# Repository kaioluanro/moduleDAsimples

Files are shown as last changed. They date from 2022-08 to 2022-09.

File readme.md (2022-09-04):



# Module D/A signal audio

Hi, it's project the module for input/output signal to computer signal.

# Features

- 5V or 3.3v power supply;
- ADC: 24bit;
- Frequence samples ADC max: 128;
- DAC: 24bit or 32bit;
- Frequence samples DAC max: 64;
- Stereo Input signal audio;
- Stereo Output signal audio;
- Connection  via i2s;

## Application 

Used for signal the audio purpose.

## Function Diagram
```mermaid
sequenceDiagram
INPUT ->> ADC: Signal
ADC->>PROCESS: 24-bits
Note over PROCESS: Process signal digital.
PROCESS->> DAC: 24-bits or 32-bits
DAC->> OUTPUT: Signal

```

## Alert
module still in test and subject to change.

## I2S for Blackpill(STM32F411CEU6)
The STMicroelectronics provides an documention know emulation I2S used SPI and TIMER. overview in the link [Emulation I2S](https://www.st.com/resource/en/application_note/an5086-i2s-protocol-emulation-on-stm32l0-series-microcontrollers-using-a-standard-spi-peripheral-stmicroelectronics.p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).

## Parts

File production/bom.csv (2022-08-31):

Designator | Footprint | Quantity | Value | LCSC Part #
C11 | C_0603_1608Metric | 1 | 100n | C80516
J7 | PinHeader_1x04_P1.27mm_Vertical | 1 | Conn_01x04 | C2935944
C7 | CP_EIA-3216-18_Kemet-A | 1 | 10u | C7171
U1 | TSSOP-20_4.4x6.5mm_P0.65mm | 1 | PCM5100APWR | C131154
C9 | CP_EIA-3216-18_Kemet-A | 1 | 10u | C7171
C4 | C_0603_1608Metric | 1 | 2.2u | C913904
C16 | CP_EIA-3216-18_Kemet-A | 1 | 10u | C7171
J6 | PinHeader_2x04_P1.27mm_Vertical | 1 | Conn_02x04_Counter_Clockwise | C541878
F1 | C_1812_4532Metric | 1 | mSMD110-16V | C69691
C22 | CP_EIA-3216-18_Kemet-A | 1 | 10u | C7171
C1 | C_0603_1608Metric | 1 | 1u | C1689
J5 | Jack_6.35mm_Neutrik_NMJ6HFD2-AU_Horizontal | 1 | PJ-625C | C309291
J2 | Jack_6.35mm_Neutrik_NMJ6HFD2-AU_Horizontal | 1 | PJ-625C | C309291
R10 | R_0603_1608Metric | 1 | 100k | C14675
C17 | C_0603_1608Metric | 1 | 100n | C80516
J1 | Jack_6.35mm_Neutrik_NMJ6HFD2-AU_Horizontal | 1 | PJ-625C | C309291
J4 | Jack_6.35mm_Neutrik_NMJ6HFD2-AU_Horizontal | 1 | PJ-625C | C309291
C5 | C_0805_2012Metric | 1 | 0.1u | C126469
D1 | D_SOD-123 | 1 | ZRE B5819W-SL | C779676
C23 | C_0603_1608Metric | 1 | 1u | C1689
C24 | C_1210_3225Metric | 1 | 10u | C92769
J3 | PinHeader_1x04_P1.27mm_Vertical | 1 | Conn_01x04 | C2935944
C14 | C_0805_2012Metric | 1 | 0.1u | C126469
C13 | C_0805_2012Metric | 1 | 0.1u | C126469
C20 | CP_EIA-3216-18_Kemet-A | 1 | 10u | C7171
R4 | R_0603_1608Metric | 1 | 5.1k | C156350
C6 | CP_EIA-3216-18_Kemet-A | 1 | 10u | C7171
R1 | R_0805_2012Metric | 1 | 2k | C269745
C25 | C_0603_1608Metric | 1 | 1u | C1689
R5 | R_0603_1608Metric | 1 | 3.3k | C72816
U2 | SSOP-20_5.3x7.2mm_P0.65mm | 1 | WM8782SEDS | C323842
U3 | SOT-23-5 | 1 | SGM2028-3.3YN5G/TR | C81088
R3 | R_0603_1608Metric | 1 | 10K | C99198
C12 | C_0603_1608Metric | 1 | 100n | C80516
R9 | R_0603_1608Metric | 1 | 100k | C14675
J8 | PinHeader_1x04_P1.27mm_Vertical | 1 | Conn_01x04 | C2935944
C21 | CP_EIA-3216-18_Kemet-A | 1 | 10u | C7171
C8 | C_0805_2012Metric | 1 | 0.1u | C126469
C2 | C_0603_1608Metric | 1 | 1u | C1689
C18 | C_0603_1608Metric | 1 | 100n | C80516
R8 | R_0603_1608Metric | 1 | 10k | C99198
R2 | R_0805_2012Metric | 1 | 2k | C269745
C10 | CP_EIA-3216-18_Kemet-A | 1 | 10u | C7171
C19 | CP_EIA-3216-18_Kemet-A | 1 | 10u | C7171
R7 | R_0603_1608Metric | 1 | 5.1k | C156350
C15 | CP_EIA-3216-18_Kemet-A | 1 | 10u | C7171
R6 | R_0603_1608Metric | 1 | 10k | C99198
C3 | C_0603_1608Metric | 1 | 2.2u | C913904

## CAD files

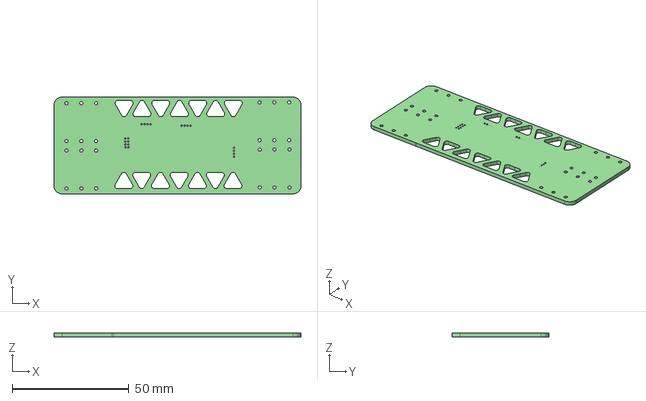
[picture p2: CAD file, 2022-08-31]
Modulo DA simple.step
105.9 x 41.5 x 1.60 mm

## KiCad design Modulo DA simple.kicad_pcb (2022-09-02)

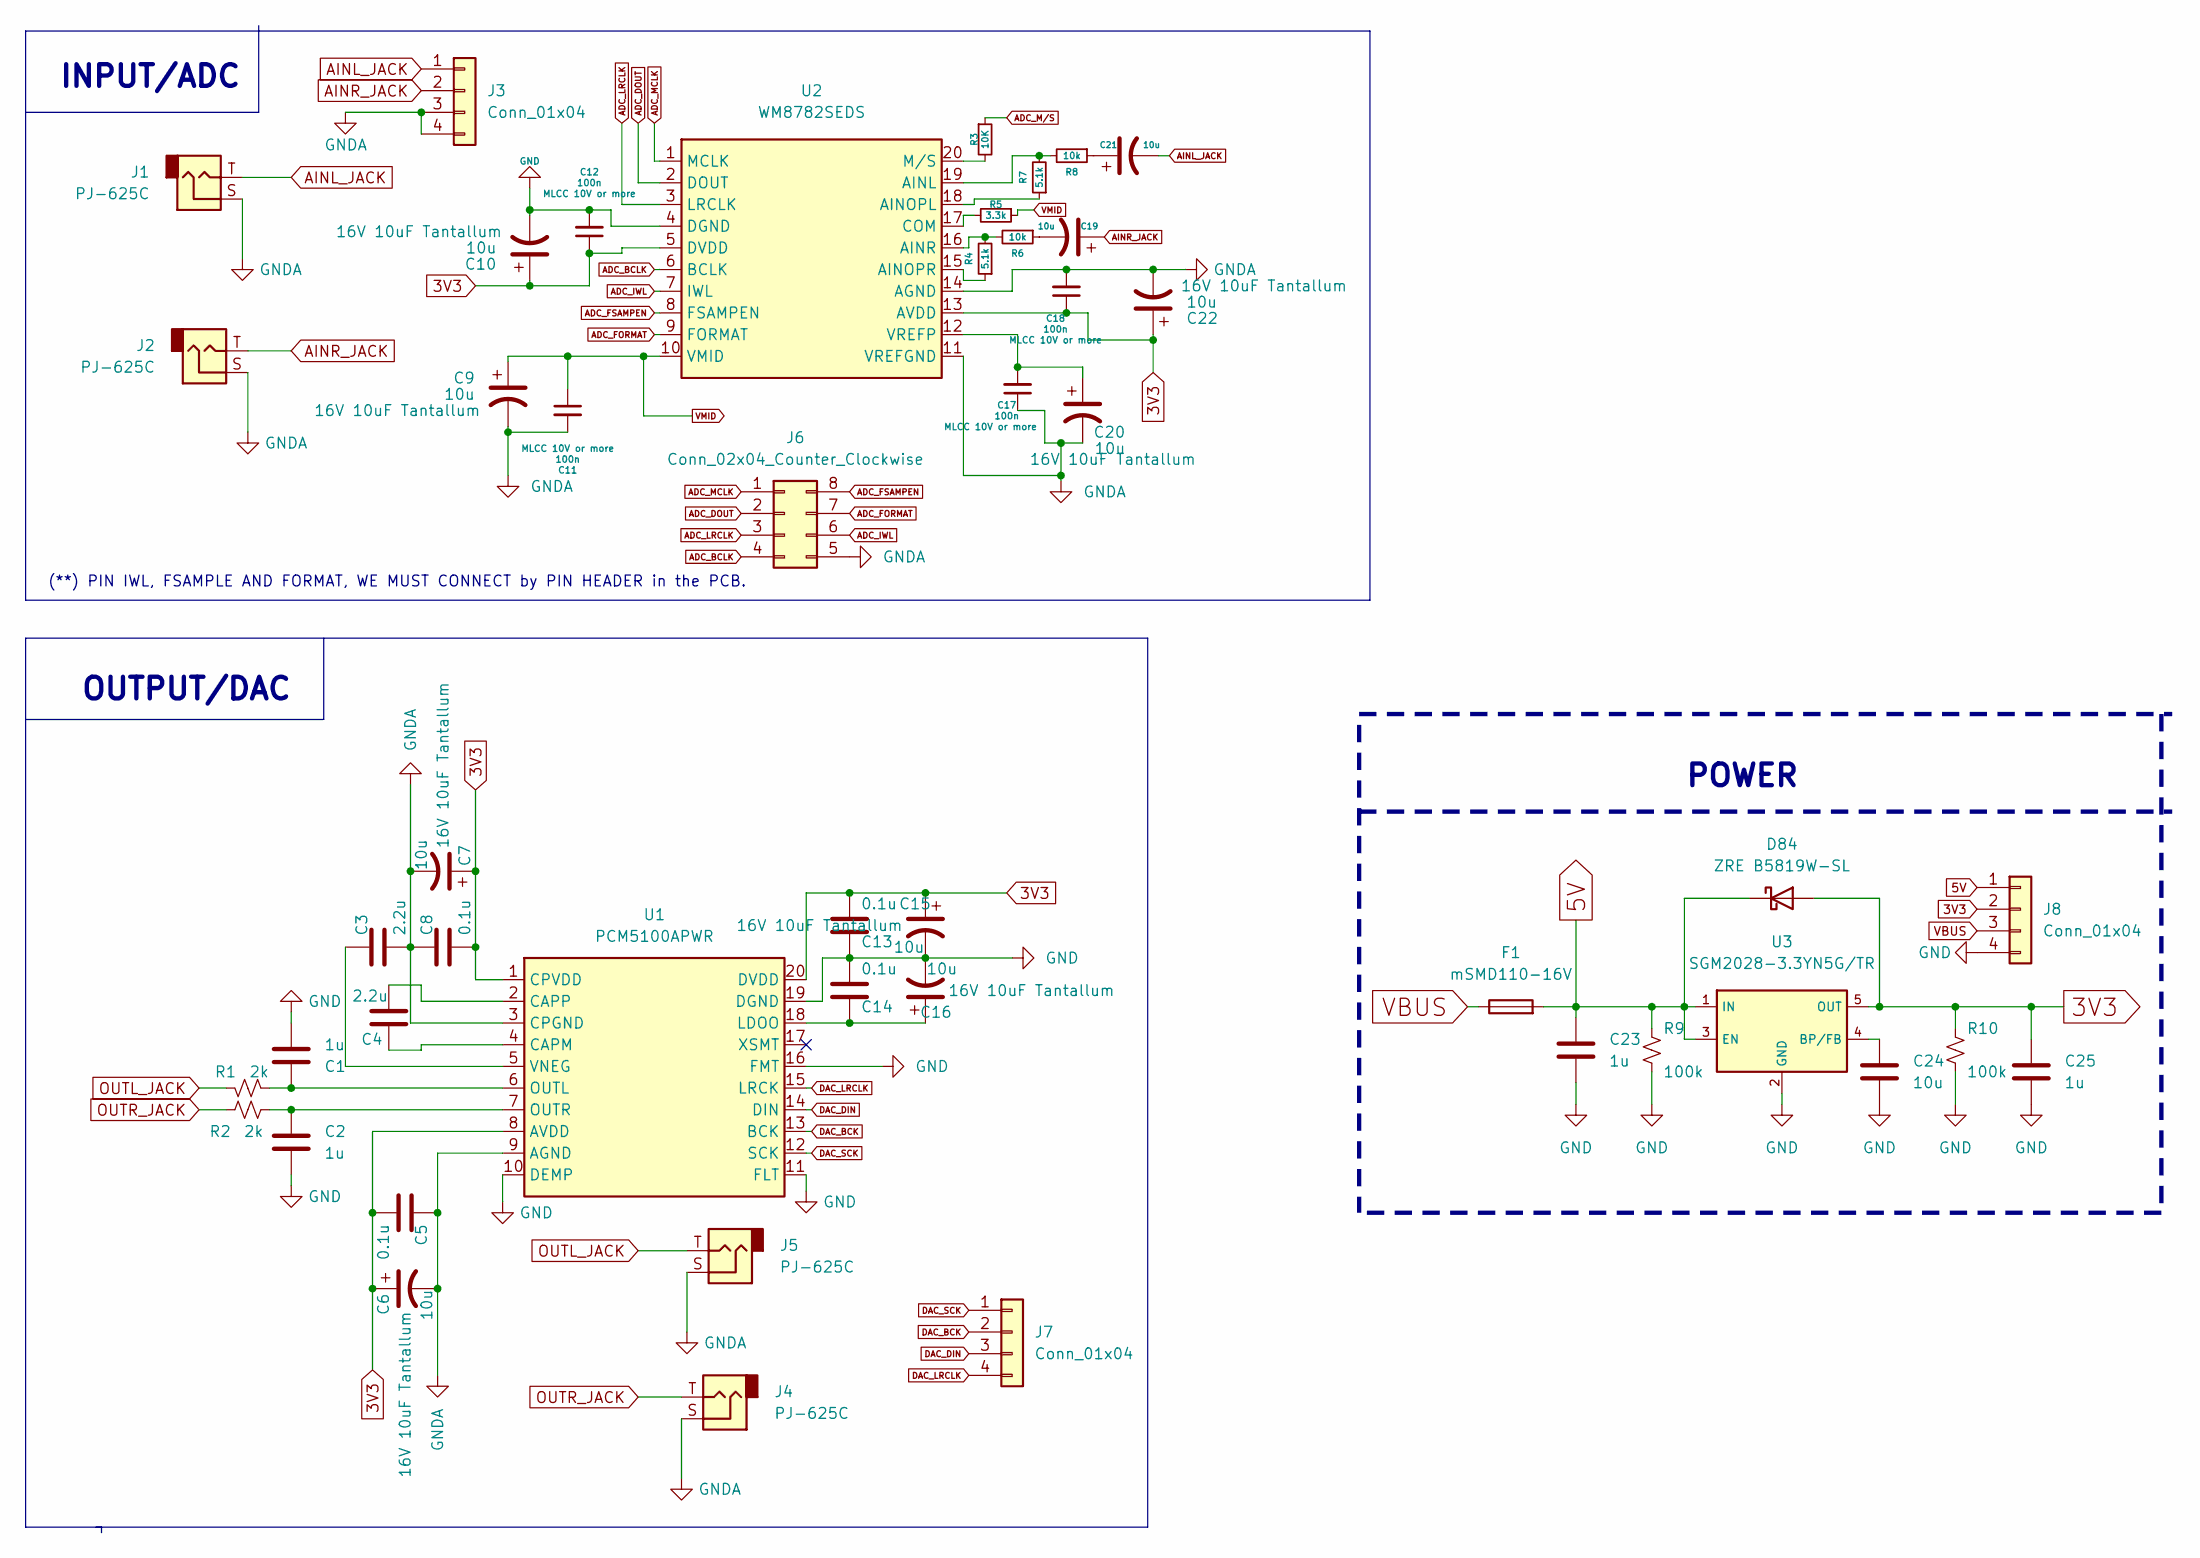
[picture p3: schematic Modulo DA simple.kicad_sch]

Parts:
C1, C2, C23, C25: 1u; C_0603_1608Metric; Manufacturer Part Number 0603F105M160NT; LCSC Part # C1689
C3, C4: 2.2u; C_0603_1608Metric; Manufacturer Part Number CL10A225KB8NNNC; LCSC Part # C913904
C5, C8, C13, C14: 0.1u; C_0805_2012Metric; Manufacturer Part Number UMK107AB7105KA-T; LCSC Part # C126469
C6, C7, C9, C10, C15, C16, C19, C20, C21, C22: 10u; CP_EIA-3216-18_Kemet-A; Manufacturer Part Number TAJA106K016RNJ; LCSC Part # C7171
C11, C12, C17, C18: 100n; C_0603_1608Metric; Manufacturer Part Number 0603B104K160CT; LCSC Part # C80516
C24: 10u; C_1210_3225Metric; Manufacturer Part Number EMK325BJ106KN-T; LCSC Part # C92769
D84: ZRE B5819W-SL; D_SOD-123; Manufacturer Part Number B5819W-SL; LCSC Part # C779676
F1: mSMD110-16V; C_1812_4532Metric; Manufacturer Part Number mSMD110-16V; LCSC Part # C69691
J1, J2, J4, J5: PJ-625C; Jack_6.35mm_Neutrik_NMJ6HFD2-AU_Horizontal; Manufacturer Part Number PJ-625C; LCSC Part # C309291
J3, J7, J8: Conn_01x04; PinHeader_1x04_P1.27mm_Horizontal; Manufacturer Part Number DZ127R-11-04-25; LCSC Part # C2935944
J6: Conn_02x04_Counter_Clockwise; PinHeader_2x04_P1.27mm_Horizontal; Manufacturer Part Number PZ127V-12-08-0720; LCSC Part # C541878
R1, R2: 2k; R_0805_2012Metric; Manufacturer Part Number RMC08052K1%N; LCSC Part # C269745
R3: 10K; R_0603_1608Metric; Manufacturer Part Number RC0603JR-0710KL; LCSC Part # C99198
R4, R7: 5.1k; R_0603_1608Metric; Manufacturer Part Number RS-03K5101FT; LCSC Part # C156350
R5: 3.3k; R_0603_1608Metric; Manufacturer Part Number RS-03K332JT; LCSC Part # C72816
R6, R8: 10k; R_0603_1608Metric; Manufacturer Part Number RC0603JR-0710KL; LCSC Part # C99198
R9, R10: 100k; R_0603_1608Metric; Manufacturer Part Number RC0603FR-07100KL; LCSC Part # C14675
U1: PCM5100APWR; TSSOP-20_4.4x6.5mm_P0.65mm; Manufacturer Part Number PCM5100APWR; LCSC Part # C131154
U2: WM8782SEDS; SSOP-20_5.3x7.2mm_P0.65mm; Manufacturer Part Number WM8782SEDS; LCSC Part # C323842
U3: SGM2028-3.3YN5G/TR; SOT-23-5; Manufacturer Part Number SGM2028-3.3YN5G/TR; LCSC Part # C81088

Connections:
3V3: C5.2, C6.1, C7.1, C8.2, C10.1, C12.1, C13.2, C15.1, C18.1, C22.1, C25.1, D84.2 (A), J8.2, R10.1, U1.1 (CPVDD), U1.8 (AVDD), U1.20 (DVDD), U2.5 (DVDD), U2.13 (AVDD), U3.5 (OUT)
5V: C23.1, D84.1 (K), F1.2, J8.1, R9.1, U3.1 (IN), U3.3 (EN); also elsewhere on the board
ADC_BCLK: J6.4, U2.6 (BCLK)
ADC_DOUT: J6.2, U2.2 (DOUT)
ADC_FORMAT: J6.7, U2.9 (FORMAT)
ADC_FSAMPEN: J6.8, U2.8 (FSAMPEN)
ADC_IWL: J6.6, U2.7 (IWL)
ADC_LRCLK: J6.3, U2.3 (LRCLK)
ADC_MCLK: J6.1, U2.1 (MCLK)
ADC_M/S: R3.1
AINL_JACK: C21.2, J1.T, J3.1
AINR_JACK: C19.1, J2.T, J3.2
DAC_BCK: J7.2, U1.13 (BCK)
DAC_DIN: J7.3, U1.14 (DIN)
DAC_LRCLK: J7.4, U1.15 (LRCK)
DAC_SCK: J7.1, U1.12 (SCK)
GND: C1.2, C2.2, C10.2, C12.2, C13.1, C14.2, C15.2, C16.2, C23.2, C24.2, C25.2, J8.4, R9.2, R10.2, U1.10 (DEMP), U1.11 (FLT), U1.16 (FMT), U1.19 (DGND), U2.4 (DGND), U3.2 (GND)
GNDA: C3.2, C5.1, C6.2, C7.2, C8.1, C9.2, C11.2, C17.1, C18.2, C20.2, C22.2, J1.S, J2.S, J3.3, J3.4, J4.S, J5.S, J6.5, U1.3 (CPGND), U1.9 (AGND), U2.11 (VREFGND), U2.14 (AGND)
unnamed: C1.1, R1.2, U1.6 (OUTL)
unnamed: C2.1, R2.2, U1.7 (OUTR)
unnamed: C3.1, U1.5 (VNEG)
unnamed: C4.1, U1.4 (CAPM)
unnamed: C4.2, U1.2 (CAPP)
unnamed: C14.1, C16.1, U1.18 (LDOO)
unnamed: C17.2, C20.1, U2.12 (VREFP)
unnamed: C19.2, R6.1
unnamed: C21.1, R8.1
unnamed: C24.1, U3.4 (BP/FB)
unnamed: R3.2, U2.20 (M/S)
unnamed: R4.1, U2.15 (AINOPR)
unnamed: R4.2, R6.2, U2.16 (AINR)
unnamed: R5.2, U2.17 (COM)
unnamed: R7.1, U2.18 (AINOPL)
unnamed: R7.2, R8.2, U2.19 (AINL)
OUTL_JACK: J5.T, R1.1
OUTR_JACK: J4.T, R2.1
VBUS: F1.1, J8.3; also elsewhere on the board
VMID: C9.1, C11.1, R5.1, U2.10 (VMID)

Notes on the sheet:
OUTPUT/DAC
POWER
(**) PIN IWL, FSAMPLE AND FORMAT, WE MUST CONNECT by PIN HEADER in the PCB.
INPUT/ADC

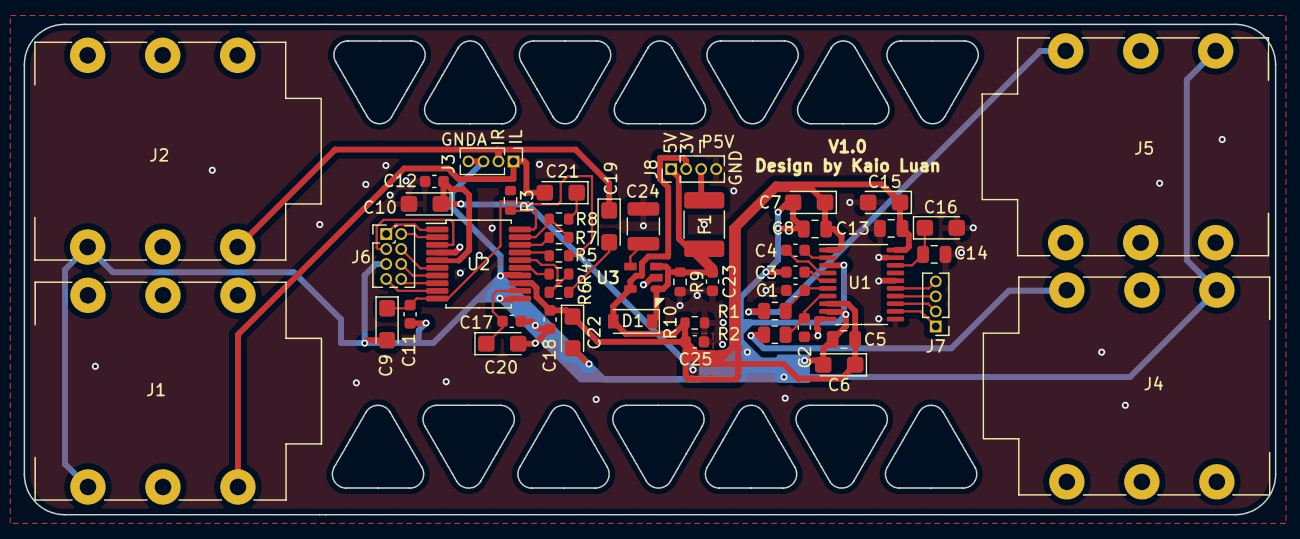
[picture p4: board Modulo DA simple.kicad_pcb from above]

Board: 2 copper layers, 105.9 x 41.5 mm, 48 parts (0 on the bottom side), 37 nets.

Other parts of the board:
F?: mSMD110-16V; C_1812_4532Metric

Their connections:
5V: F?.2; also elsewhere on the board
VBUS: F?.1; also elsewhere on the board

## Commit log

2022-08-31 add gnd and gnda in the pcb
    [Modulo DA simple.kicad_pcb, bom.csv, designators.csv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]
2022-08-31 Boom the lcsc
    [LCSC_Exported_20220901_025620.csv]
2022-09-02 02092022
    Check and connection some components
    [Modulo DA simple.kicad_pcb]
2022-09-02 02092022-2
    Send for plot pcb
    [Modulo DA simple.kicad_pcb]
